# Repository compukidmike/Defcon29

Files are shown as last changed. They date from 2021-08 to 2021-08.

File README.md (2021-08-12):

# DEF CON 29 Badge
by MK Factor

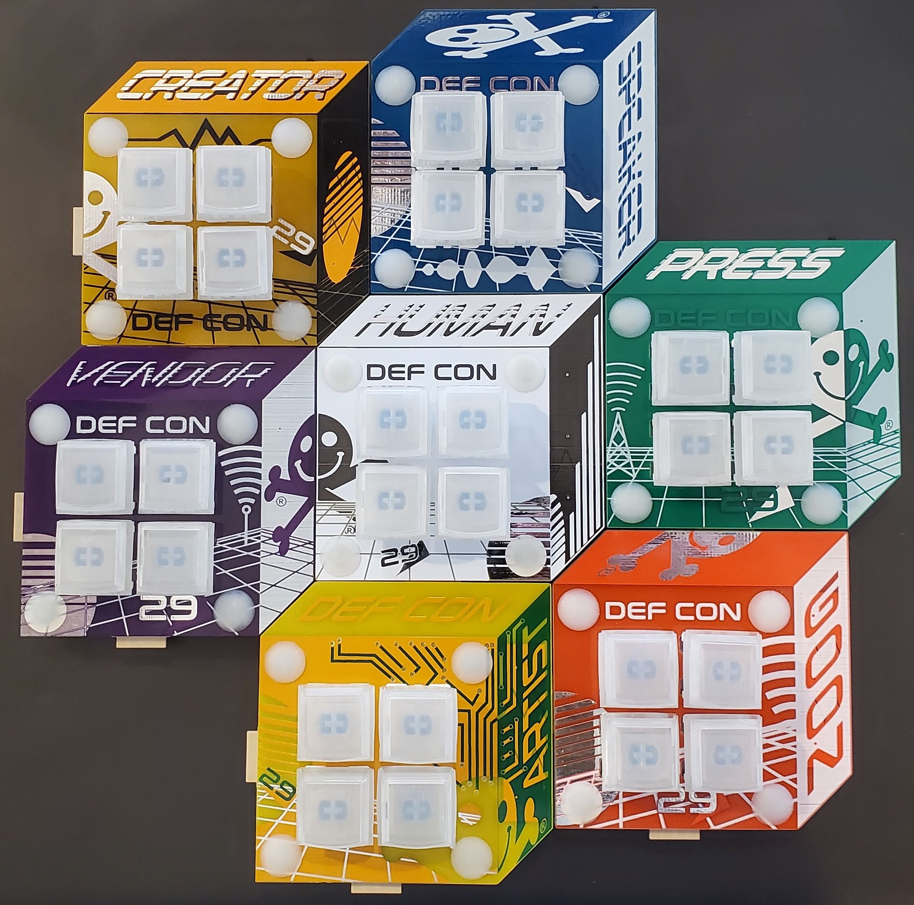
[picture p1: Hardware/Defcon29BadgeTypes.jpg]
Badge Types


Here's the code and some design files for the DEF CON 29 badge. Feel free to modify and share to your heart's content.

Compiled .uf2 files can be found under Firmware/Compiled. These are the firmware files that were released during the con that fix the 31-character issue. To put them on your badge, hold the bottom-right button when plugging it into your computer. The badge will start up in bootloader mode and will appear as a mass storage device. Drag/Drop or Copy/Paste the new .uf2 file onto the badge. It will apply the new firmware and automatcially restart.

NOTE: Flashing new firmware should not reset your challenge/game stats. They are stored in a separate EEPROM location in flash.

To generate your own .uf2 files, take the compiled .hex file and use the UF2 converter uf2conv.py available from https://github.com/microsoft/uf2/ (in the utils directory).

I wrote the code in ~~Atmel~~Microchip Studio 7.0 and used the ASF Framework. The install files for the version I used is available on the DEF CON Media Server
https://media.defcon.org/DEF%20CON%2029/DEF%20CON%2029%20badge/

The main microcontroller is an ATSAMD21G16B. It has 64KB of flash and 8KB of RAM. The first 8KB of flash is used for the bootloader, leaving 56KB for the main program. The bootloader is write protected by internal fuses in the microcontroller. If you want to remove it, you'll need to use an SWD programmer or write your own program that unlocks the booloader section and erases/overwrites it. Do this at your own risk.

Pull requests *may* be merged if they add functionality while retaining all original functionality. If you make something cool that doesn't fit this description, let me know and I'll try to add it to the list here.

## Cool Things Other People Have Made For The Badge ##
(I have not verified/tested any of these. Use at your own risk) 
* Music - https://github.com/duck-37/dc29-badge-stuff

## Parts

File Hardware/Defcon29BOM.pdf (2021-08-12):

DEF CON 29 Badge BOM
Bottom Side
Item | Qty Reference | Manufacturer | Manuf. Part # | Link
1 | 1 BT1 | Keystone Electronics | 3034TR | https://www.digikey.com/product-detail/en/keystone-electronics/3034TR/36-3034CT-ND/4833649
2 | 1 J5 | Adam Tech | USB-A-S-RA-TSMT | https://www.digikey.com/product-detail/en/adam-tech/USB-A-S-RA-TSMT/2057-USB-A-S-RA-TSMT-ND/9832331
3 | 4 SW1, SW2, SW3, SW4 | Gateron | KS-2P02B01-01 | https://kbdfans.com/products/gateron-hot-swap-pcb-socket

Top Side
Item | Qty Reference | Manufacturer | Manuf. Part # | Link
1 | 1 BZ1 | Murata Electronics | PKMCS0909E4000-R1 | https://www.digikey.com/product-detail/en/murata-electronics/PKMCS0909E4000-R1/490-9647-1-ND/4878401
2 | 4 C1, C2, C3, C4 | Kemet | C0603C104M4RACTU | https://www.digikey.com/en/products/detail/kemet/C0603C104M4RACTU/411098
3 | 3 C5, C6, C7 | Samsung Electro-Mechanics CL10A105KQ8NNNC | https://www.digikey.com/en/products/detail/samsung-electro-mechanics/CL10A105KQ8NNNC/3886694
4 | 4 D1, D2, D3, D4 | Everlight Electronics Co Ltd | 19-337C/RSBHGHC-A88/4T | https://www.digikey.com/en/products/detail/everlight-electronics-co-ltd/19-337C-RSBHGHC-A88-4T/10059590
5 | 2 J1, J3 | AVX Corporation | 109159004101116 | https://www.digikey.com/product-detail/en/avx-corporation/109159004101116/478-5675-1-ND/2080204
6 | 2 J2, J4 | AVX Corporation | 209159004101116 | https://www.digikey.com/product-detail/en/avx-corporation/209159004101116/478-5680-1-ND/2080209
7 | 3 RN1, RN2, RN3 | Bourns Inc. | CAY16-100J4LF | https://www.digikey.com/en/products/detail/bourns-inc/CAY16-100J4LF/3437837
8 | 1 RN4 | Bourns Inc. | CAY16-512J4LF | https://www.digikey.com/product-detail/en/bourns-inc/CAY16-512J4LF/CAY16-512J4LFCT-ND/3767810
9 | 2 | RN5, RN6 | Bourns Inc. | CAY16-101J4LF | https://www.digikey.com/en/products/detail/bourns-inc/CAY16-101J4LF/3437835
10 | 3 | SLIDER1, SLIDER2, SLIDER3 | ITT Cannon, LLC | 120220-0206 | https://www.digikey.com/product-detail/en/itt-cannon-llc/120220-0206/1003-1012-1-ND/2404035
11 | 1 | SW5 | C&K | JS202011JAQN | https://www.digikey.com/product-detail/en/c-k/JS202011JAQN/CKN10722CT-ND/6137636
12 | 1 | U1 | Microchip | ATSAMD21G16B-AU | https://www.digikey.com/en/products/detail/microchip-technology/ATSAMD21G16B-AU/5325402
13 | 1 | U2 | ON Semiconductor | NCP115ASN330T2G | https://www.digikey.com/product-detail/en/on-semiconductor/NCP115ASN330T2G/NCP115ASN330T2GOSCT-ND/9764887
14 | 1 | U3 | Torex Semiconductor Ltd | XBP15SRV05W-G | https://www.digikey.com/product-detail/en/torex-semiconductor-ltd/XBP15SRV05W-G/893-1422-1-ND/8256124
15 | 1 | X1 | IC components Store | Unknown | https://www.aliexpress.com/item/32962997618.html

Other Parts
Item | Qty | Reference | Manufacturer | Manuf. Part # | Link
1 | 4 | Keyswitches 1-4 | Gateron | Gateron Blue SMD | https://kbdfans.com/collections/gateron-swithes/products/smd-gateron-swtich
2 | 4 | Spacers 1-4 | transkoot | G216-03 | https://www.aliexpress.com/item/32844434973.html
3 | 4 | Keycaps 1-4 | MK Factor | Custom | STL available on DEF CON Media Server

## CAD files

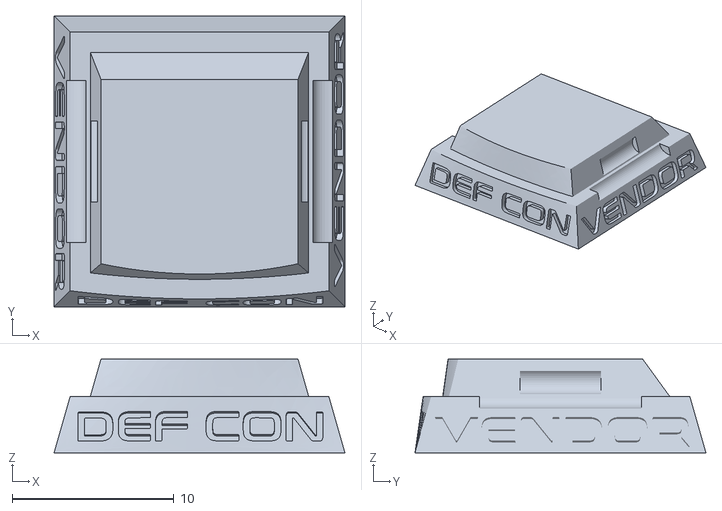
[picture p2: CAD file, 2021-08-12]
Hardware/Keycaps/Keycap-Bottom-Vendor.stl
18.0 x 18.0 x 5.80

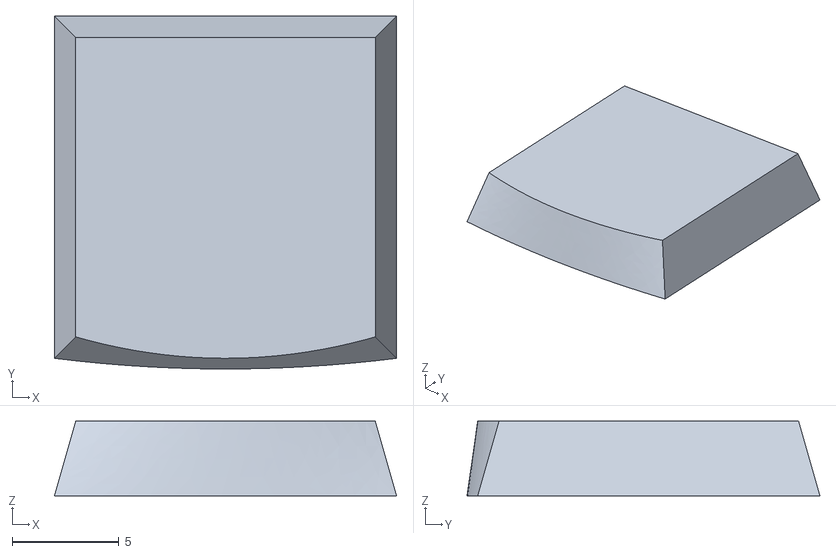
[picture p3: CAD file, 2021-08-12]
Hardware/Keycaps/Keycap-Top.stl
16.0 x 16.5 x 3.50

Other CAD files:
Hardware/Keycaps/Keycap-Bottom-Press.stl
Hardware/Keycaps/Keycap-Bottom-Artist.stl
Hardware/Keycaps/Keycap-Bottom-Human.stl
Hardware/Keycaps/Keycap-Bottom-Creator.stl
Hardware/Keycaps/Keycap-Source-FreeCad.FCStd
Hardware/Keycaps/Keycap-Bottom-Goon.stl
Hardware/Keycaps/Keycap-Bottom-Speaker.stl

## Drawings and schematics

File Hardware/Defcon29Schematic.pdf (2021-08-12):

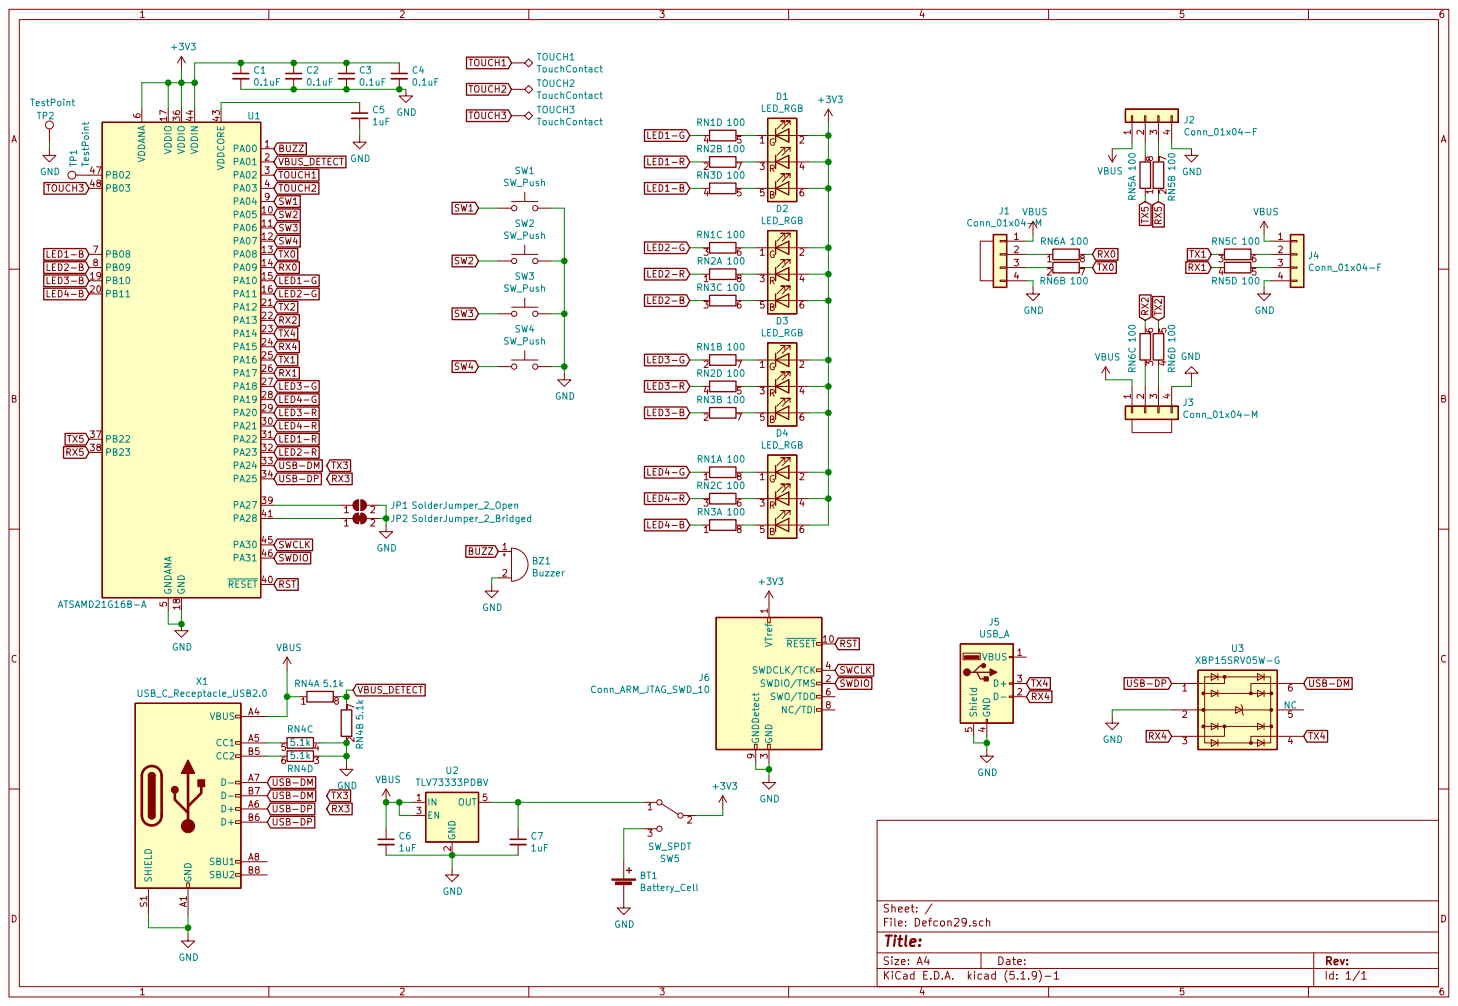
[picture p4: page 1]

2 EN 3 OUT 5 U2 TLV73333PDBV GND GND
SW4 SW_Push C7

3 SWDCLK/TCK 4 SWO/TDO 6 NC/TDI 8 GNDDetect 9

Id: 1/1 Title: File: Defcon29.sch Sheet: / GND

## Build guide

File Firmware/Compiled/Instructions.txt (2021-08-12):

The dc29boot.hex is the bootloader. It requires a SWD programmer connected to the Tag-Connect port on the badge. This only needs to be done once on a new chip.
The .uf2 files can be flashed with just a USB cable. Hold the bottom-right button when connecting the USB cable. The badge will enter the bootloader (top-left LED will blink red). It will appear as a mass storage device on your computer. You can then drag/drop the new uf2 firmware file onto it. The badge will automatically reboot when the update is complete.
NOTE: flashing new firmware will NOT reset your challenge/game status (unless you create custom firmware to overwrite the EEPROM).

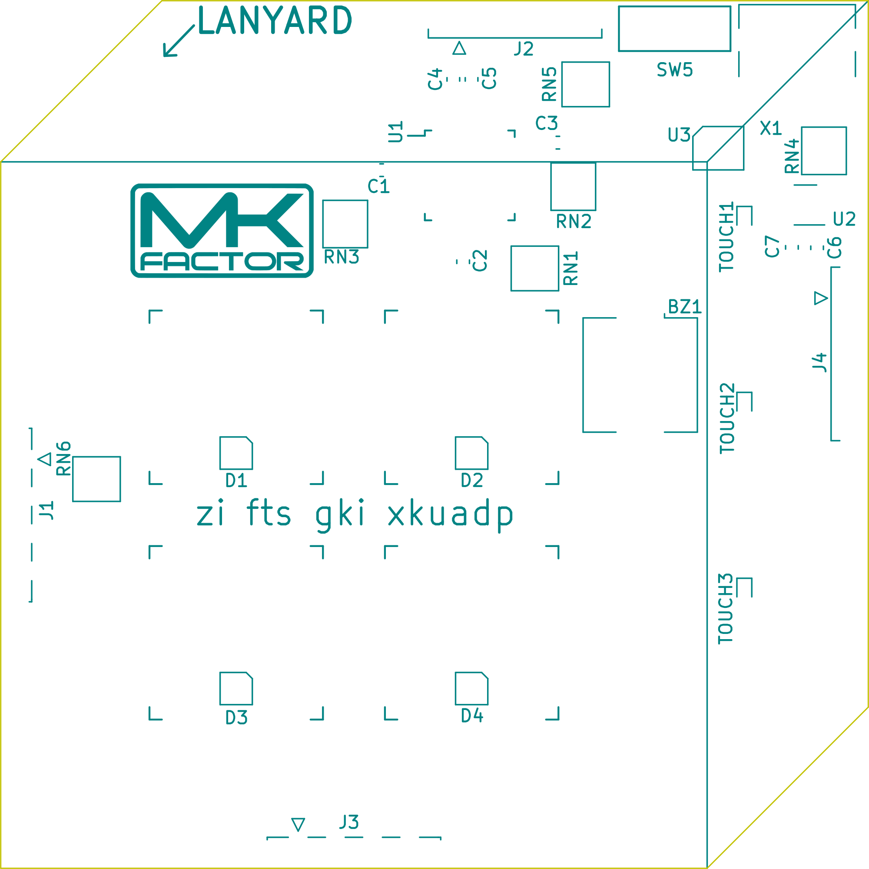
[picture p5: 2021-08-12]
Hardware/Defcon29-TopAssembly.png

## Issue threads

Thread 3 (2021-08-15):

Simon says sounds

miketweaver, 2021-08-15:
When you play Simon says the sound the game makes and then when you press the button aren't the same.

This probably is a bug

compukidmike, 2021-08-15:
This is a very interesting problem. The buzzer code is exactly the same for both, so I'm not sure why there's a difference. The main oscillator varies a lot with battery voltage, so that's possibly where it's coming from, but the LED is on in both situations, so it should be the same. If anyone has ideas, I'm all ears.

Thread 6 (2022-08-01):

Request: USB bulk transfer

skintigh, 2022-08-01:
I'd like to modify a button so the badge can connect to a USB peripheral that appears as a "mass storage device" and then do a number of sequences of reads and writes of 16 or 31 bytes. I know the vendor/device IDs.

Are there any examples you could share or pointers you could give me around MSC or bulk transfers?

I see you've commented out a lot of code dealing with udi_msc. I assume undoing that is the first step, then finding/following examples.
Thanks!

compukidmike, 2022-08-01:
I never played with the host mode, only device mode. In Microchip Studio, the ASF Wizard will allow you to add the necessary modules for USB host mode. The udc_stop() command should turn off the USB device mode so that you can re-configure the USB hardware for host mode. Good luck!

skintigh, 2022-08-03:
Do you have any hints on how to write raw data to USB?

I've gone through their docs and tried dozens of functions. They have 440 functions for reading/writing bytes to USB, and not a single working example nor description of required setup that I can find.

compukidmike, 2022-08-03:
Unfortunately I don't, sorry. I just used the USB serial example and slightly modified it for my needs.

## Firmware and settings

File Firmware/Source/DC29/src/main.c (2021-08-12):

/**
 * \file
 *
 * \brief Main functions for Keyboard example
 *
 * Copyright (c) 2009-2018 Microchip Technology Inc. and its subsidiaries.
 *
 * \asf_license_start
 *
 * \page License
 *
 * Subject to your compliance with these terms, you may use Microchip
 * software and any derivatives exclusively with Microchip products.
 * It is your responsibility to comply with third party license terms applicable
 * to your use of third party software (including open source software) that
 * may accompany Microchip software.
 *
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
 * \asf_license_stop
 *
 */
/*
 * Support and FAQ: visit <a href="https://www.microchip.com/support/">Microchip Support</a>
 */

#include <asf.h>
#include <stdbool.h>
#include "main.h"
#include "conf_usb.h"
#include "udi_hid_kbd.h"
#include "ui.h"

#include <pinmux.h>
#include <nvm.h>
#include "pwm.h"
#include <rww_eeprom.h>
#include "keys.h"
#include "serialconsole.h"
#include "games.h"



static volatile bool main_b_kbd_enable = false;

enum status_code eepromstatus;

/**
 * RTC Interrupt timing definition
 */
#define TIME_PERIOD_1MSEC 33u
#define TIME_PERIOD_500MSEC 16500u
/**
 * Variables
 */

uint32_t serialnum[4];

bool USBPower = false;


uint8_t rotor_state;
uint8_t rotor_position;
volatile uint8_t PWM_Count;
volatile uint32_t touch_time_counter = 0u;
struct rtc_module rtc_instance;

volatile uint32_t millis = 0;

volatile uint32_t buzzer_counter = 0;
volatile uint32_t buzzer_overflow = 250;
volatile bool buzzer_state = false;
volatile bool buzzer_skip = false;

bool main_b_cdc_enable = false;

uint8_t led1color[3];
uint8_t led2color[3];
uint8_t led3color[3];
uint8_t led4color[3];
uint8_t led1pressedcolor[3];
uint8_t led2pressedcolor[3];
uint8_t led3pressedcolor[3];
uint8_t led4pressedcolor[3];

volatile bool wait_for_sof = false;

volatile bool button1 = false;
volatile bool button2 = false;
volatile bool button3 = false;
volatile bool button4 = false;

#define DEBOUNCE_TIME 200
volatile uint32_t lastButton1Press = 0;
volatile uint32_t lastButton2Press = 0;
volatile uint32_t lastButton3Press = 0;
volatile uint32_t lastButton4Press = 0;

uint8_t keymap[231];
uint8_t keymaplength;
uint8_t keymapstarts[6];

uint8_t fwversion[1];

serial serialnumlist;

//Challenge challengedata;
ChallengeStruct challengedata;

//Game gamedata;
GameStruct gamedata;

GameModes gamemode;

extern struct tcc_module tcc2_instance;

volatile bool games_buzzer_off = true;
volatile uint32_t last_usb_comms = 0;

/* Macros */

/**
 * \def GET_SENSOR_STATE(SENSOR_NUMBER)
 * \brief To get the sensor state that it is in detect or not
 * \param SENSOR_NUMBER for which the state to be detected
 * \return Returns either 0 or 1
 * If the bit value is 0, it is not in detect
 * If the bit value is 1, it is in detect
 * Alternatively, the individual sensor state can be directly accessed using
 * p_qm_measure_data->p_sensor_states[(SENSOR_NUMBER/8)] variable.
 */
 #define GET_SELFCAP_SENSOR_STATE(SENSOR_NUMBER) p_selfcap_measure_data-> \
	p_sensor_states[(SENSOR_NUMBER / \
	8)] & (1 << (SENSOR_NUMBER % 8))

/**
 * \def GET_ROTOR_SLIDER_POSITION(ROTOR_SLIDER_NUMBER)
 * \brief To get the rotor angle or slider position.
 * These values are valid only when the sensor state for
 * corresponding rotor or slider shows in detect.
 * \param ROTOR_SLIDER_NUMBER for which the position to be known
 * \return Returns rotor angle or sensor position
 */
#define GET_SELFCAP_ROTOR_SLIDER_POSITION(ROTOR_SLIDER_NUMBER) \
	p_selfcap_measure_data->p_rotor_slider_values[ \
		ROTOR_SLIDER_NUMBER]


/* Interrupt on "pin change" from push button to do wakeup on USB
 * Note:
 * This interrupt is enable when the USB host enable remote wakeup feature
 * This interrupt wakeup the CPU if this one is in idle mode
 */
/*static void ui_wakeup_handler(void)
{
	// It is a wakeup then send wakeup USB 
	udc_remotewakeup();
	//LED_On(PIN_PA19);
}*/

void vbus_handler(void){
	if(port_pin_get_input_level(USB_VBUS_PIN)){
		// Start USB stack to authorize VBus monitoring
		disable_usart_top();
		udc_start();
		USBPower = true;
		//configure_usart_top_default();
	} else {
		//disable_usart_top();
		udc_stop();
		configure_usart_top_usb();
		USBPower = false;
	}
}

/*! \brief Main function. Execution starts here.
 */
int main(void)
{
	//Get chip serial number. We only use the last 4 bytes to save EEPROM space and to make comms faster
	serialnum[0] = *(volatile uint32_t *)0x0080A040;
	serialnum[1] = *(volatile uint32_t *)0x0080A044;
	serialnum[2] = *(volatile uint32_t *)0x0080A048;
	serialnum[3] = *(volatile uint32_t *)0x0080A00C;
	
	eepromstatus = rww_eeprom_emulator_init();
	if(eepromstatus == STATUS_ERR_BAD_FORMAT){
		rww_eeprom_emulator_erase_memory();
		rww_eeprom_emulator_init();
	}

	rww_eeprom_emulator_read_buffer(EEP_FIRMWARE_VERSION, fwversion, 1);
	
	if(fwversion[0] != FIRMWARE_VERSION){ //Clear eeprom and re-init with good values
		reset_eeprom();
	}
	
	read_eeprom();
	
	
	//uint8_t button1_state;
	//uint8_t button2_state;
	uint8_t slider_state;
	uint8_t slider_position;
	uint8_t last_slider_position;
	
	irq_initialize_vectors();
	cpu_irq_enable();

	// Initialize the sleep manager
	//sleepmgr_init();

#if !SAM0
	sysclk_init();
	board_init();
#else
	system_init();
#endif

	//Enable GCLK Generator 3
	SYSCTRL->VREG.bit.RUNSTDBY = 1;
	
	// Configure GCLK3's divider - in this case, no division - so just divide by one /
	GCLK->GENDIV.reg =
	GCLK_GENDIV_ID(3) |
	GCLK_GENDIV_DIV(1);

	// Setup GCLK3 using the internal 8 MHz oscillator /
	GCLK->GENCTRL.reg =
	GCLK_GENCTRL_ID(3) |
	GCLK_GENCTRL_SRC_OSC8M |
	// Improve the duty cycle. /
	GCLK_GENCTRL_IDC |
	GCLK_GENCTRL_GENEN |
	GCLK_GENCTRL_RUNSTDBY;

	// Wait for the write to complete /
	while(GCLK->STATUS.bit.SYNCBUSY) {};
		
	// Connect GCLK3 to SERCOM0 /
	GCLK->CLKCTRL.reg =
	GCLK_CLKCTRL_CLKEN |
	GCLK_CLKCTRL_GEN_GCLK3 |
	GCLK_CLKCTRL_ID_SERCOM0_CORE;

	// Wait for the write to complete. /
	while (GCLK->STATUS.bit.SYNCBUSY) {};
	
	delay_init();
	sleepmgr_init();
	
	
	struct port_config pin_conf;
	port_get_config_defaults(&pin_conf);
	

	/* Set buttons as inputs */
	pin_conf.direction  = PORT_PIN_DIR_INPUT;
	pin_conf.input_pull = PORT_PIN_PULL_UP;
	port_pin_set_config(BUTTON1, &pin_conf);
	port_pin_set_config(BUTTON2, &pin_conf);
	port_pin_set_config(BUTTON3, &pin_conf);
	port_pin_set_config(BUTTON4, &pin_conf);
	
	port_pin_set_config(MATRIX, &pin_conf);
	port_pin_set_config(MAX, &pin_conf);
	port_pin_set_config(ALIENS, &pin_conf);
	
	pin_conf.input_pull = PORT_PIN_PULL_DOWN;
	port_pin_set_config(USB_VBUS_PIN, &pin_conf);
	
	
	//Setup Pin Interrupts
	struct extint_chan_conf config_extint_chan;
	extint_chan_get_config_defaults(&config_extint_chan);
	
	//VBUS pin interrupt
	config_extint_chan.gpio_pin            = PIN_PA01A_EIC_EXTINT1;
	config_extint_chan.gpio_pin_mux        = PINMUX_PA01A_EIC_EXTINT1;
	config_extint_chan.gpio_pin_pull       = EXTINT_PULL_DOWN;
	config_extint_chan.filter_input_signal = true;
	config_extint_chan.detection_criteria  = EXTINT_DETECT_BOTH;
	extint_chan_set_config(1, &config_extint_chan);
	extint_register_callback(vbus_handler, 1, EXTINT_CALLBACK_TYPE_DETECT);
	extint_chan_enable_callback(1,EXTINT_CALLBACK_TYPE_DETECT);

	//Button 1 interrupt
	config_extint_chan.gpio_pin            = PIN_PA04A_EIC_EXTINT4;
	config_extint_chan.gpio_pin_mux        = PINMUX_PA04A_EIC_EXTINT4;
	config_extint_chan.gpio_pin_pull       = EXTINT_PULL_UP;
	config_extint_chan.filter_input_signal = true;
	config_extint_chan.detection_criteria  = EXTINT_DETECT_FALLING;
	extint_chan_set_config(4, &config_extint_chan);
	extint_register_callback(button1_handler, 4, EXTINT_CALLBACK_TYPE_DETECT);
	extint_chan_enable_callback(4,EXTINT_CALLBACK_TYPE_DETECT);
	
	//Button 2 interrupt
	config_extint_chan.gpio_pin            = PIN_PA05A_EIC_EXTINT5;
	config_extint_chan.gpio_pin_mux        = PINMUX_PA05A_EIC_EXTINT5;
	config_extint_chan.gpio_pin_pull       = EXTINT_PULL_UP;
	config_extint_chan.filter_input_signal = true;
	config_extint_chan.detection_criteria  = EXTINT_DETECT_FALLING;
	extint_chan_set_config(5, &config_extint_chan);
	extint_register_callback(button2_handler, 5, EXTINT_CALLBACK_TYPE_DETECT);
	extint_chan_enable_callback(5,EXTINT_CALLBACK_TYPE_DETECT);
	
	//Button 3 interrupt
	config_extint_chan.gpio_pin            = PIN_PA06A_EIC_EXTINT6;
	config_extint_chan.gpio_pin_mux        = PINMUX_PA06A_EIC_EXTINT6;
	config_extint_chan.gpio_pin_pull       = EXTINT_PULL_UP;
	config_extint_chan.filter_input_signal = true;
	config_extint_chan.detection_criteria  = EXTINT_DETECT_FALLING;
	extint_chan_set_config(6, &config_extint_chan);
	extint_register_callback(button3_handler, 6, EXTINT_CALLBACK_TYPE_DETECT);
	extint_chan_enable_callback(6,EXTINT_CALLBACK_TYPE_DETECT);
	
	//Button 4 interrupt
	config_extint_chan.gpio_pin            = PIN_PA07A_EIC_EXTINT7;
	config_extint_chan.gpio_pin_mux        = PINMUX_PA07A_EIC_EXTINT7;
	config_extint_chan.gpio_pin_pull       = EXTINT_PULL_UP;
	config_extint_chan.filter_input_signal = true;
	config_extint_chan.detection_criteria  = EXTINT_DETECT_FALLING;
	extint_chan_set_config(7, &config_extint_chan);
	extint_register_callback(button4_handler, 7, EXTINT_CALLBACK_TYPE_DETECT);
	extint_chan_enable_callback(7,EXTINT_CALLBACK_TYPE_DETECT);
	
	timer_init();
	
	configure_usart();
	configure_usart_callbacks();
	
	
	if(port_pin_get_input_level(USB_VBUS_PIN)){
		// Start USB stack to authorize VBus monitoring
		//disable_usart_top();
		udc_start();
		USBPower = true;
		//configure_usart_top_default();
		} else {
		//disable_usart_top();
		//udc_stop();
		configure_usart_top_usb();
		USBPower = false;
	}
	
	GCLK->GENCTRL.bit.RUNSTDBY = 1;  //GCLK run standby
	
	touch_sensors_init();
	
	pwm_init();
	
	//Startup LED Sequence
	uint8_t delaytime = 40;
	led_on(LED1R);
	delay_cycles_ms(delaytime);
	led_on(LED2R);
	delay_cycles_ms(delaytime);
	led_on(LED3R);
	delay_cycles_ms(delaytime);
	led_on(LED4R);
	delay_cycles_ms(delaytime);
	led_off(LED1R);
	led_on(LED1G);
	delay_cycles_ms(delaytime);
	led_off(LED2R);
	led_on(LED2G);
	delay_cycles_ms(delaytime);
	led_off(LED3R);
	led_on(LED3G);
	delay_cycles_ms(delaytime);
	led_off(LED4R);
	led_on(LED4G);
	delay_cycles_ms(delaytime);
	led_off(LED1G);
	led_on(LED1B);
	delay_cycles_ms(delaytime);
	led_off(LED2G);
	led_on(LED2B);
	delay_cycles_ms(delaytime);
	led_off(LED3G);
	led_on(LED3B);
	delay_cycles_ms(delaytime);
	led_off(LED4G);
	led_on(LED4B);
	delay_cycles_ms(delaytime);
	led_off(LED1B);
	delay_cycles_ms(delaytime);
	led_off(LED2B);
	delay_cycles_ms(delaytime);
	led_off(LED3B);
	delay_cycles_ms(delaytime);
	led_off(LED4B);
	
	if(!port_pin_get_input_level(BUTTON1)){
		gamemode = SIMON_SOLO;
		led_set_color(1,LED_COLOR_OFF);
		led_set_color(2,LED_COLOR_OFF);
		led_set_color(3,LED_COLOR_OFF);
		led_set_color(4,LED_COLOR_OFF);
		while(port_pin_get_input_level(BUTTON1) == false);
		button1 = false;
	}

	uart_event = millis;
	
	led_set_color(1,led1color);
	led_set_color(2,led2color);
	led_set_color(3,led3color);
	led_set_color(4,led4color);

	
	while(1){
		//Check Buttons
		if(gamemode == IDLE){ //Game modes check the buttons themselves
			if(USBPower && ((millis - last_usb_comms) < 100)){ //Only send keys when connected to a computer
				if(button1){
					button1 = false;
					//if(main_b_kbd_enable) send_keys(1);
					send_keys(1);
				}
				if(button2){
					button2 = false;
					//if(main_b_kbd_enable) send_keys(2);
					send_keys(2);
				}
				if(button3){
					button3 = false;
					//if(main_b_kbd_enable) send_keys(3);
					send_keys(3);
				}
				if(button4){
					button4 = false;
					//if(main_b_kbd_enable) send_keys(4);
					send_keys(4);
				}
			
				//Check Touch Sensors
				touch_sensors_measure();
				if (p_selfcap_measure_data->measurement_done_touch == 1u) {

					p_selfcap_measure_data->measurement_done_touch = 0u;
					slider_state = GET_SELFCAP_SENSOR_STATE(0);
					if(slider_state)
					{
						slider_position = GET_SELFCAP_ROTOR_SLIDER_POSITION(0);
						if(slider_position > last_slider_position + 10){
							last_slider_position = slider_position;
							send_keys(6);//sliding down
						}
						if(slider_position < last_slider_position - 10){
							last_slider_position = slider_position;
							send_keys(5);//sliding up
						}
					}
				}
			}
		}
		
		//Update USB serial console if we got data
		if(main_b_cdc_enable){
			if(udi_cdc_get_nb_received_data()){
				updateSerialConsole();
			}
		}
		
		//Go to sleep to save battery
		//if (!USBPower && ((uart_event + 1000) < millis)) {
		if (!USBPower && ((millis - uart_event) > 1000) && gamemode != SIMON_SOLO) {
			standby_sleep();
		}
		
		
		//Check serial ports
		check_comms();
		
		run_games();
		
		play_sounds();
	}
}


void send_data(void){
	const uint16_t data = 1;
	uint8_t delay = 50;
	usart_write_job(&usart_top_instance, &data);
	delay_cycles_ms(delay);
	usart_write_job(&usart_right_instance, &data);
	delay_cycles_ms(delay);
	usart_write_job(&usart_bottom_instance, &data);
	delay_cycles_ms(delay);
	usart_write_job(&usart_left_instance, &data);
	delay_cycles_ms(delay);
	usart_write_job(&usart_usba_instance, &data);
	delay_cycles_ms(delay);
	usart_write_job(&usart_usbc_instance, &data);
	delay_cycles_ms(delay);
}

void main_suspend_action(void)
{
	//ui_powerdown();
}

void main_resume_action(void) 
{
	//ui_wakeup();
}

//void main_sof_action(void)
void user_callback_sof_action(void)
{
	wait_for_sof = false;
	last_usb_comms = millis;
}

void main_remotewakeup_enable(void)
{
	//ui_wakeup_enable();
}

void main_remotewakeup_disable(void)
{
	//ui_wakeup_disable();
}

//bool main_kbd_enable(void)
void user_callback_vbus_action(bool b_vbus_high)
{
	main_b_kbd_enable = b_vbus_high;
	if(main_b_kbd_enable){
		disable_usart_top();
		configure_usart_top_default();
	} else {
		disable_usart_top();
		configure_usart_top_usb();
	}
}

void main_kbd_disable(void)
{
	main_b_kbd_enable = false;
}

/*! \brief Configure the RTC timer overflow callback
 *
 */
void rtc_overflow_callback(void)
{
	millis ++;
	
	/* Do something on RTC overflow here */
	if(touch_time_counter == touch_time.measurement_period_ms)
	{
		touch_time.time_to_measure_touch = 1;
		touch_time.current_time_ms = touch_time.current_time_ms +
		touch_time.measurement_period_ms;
		touch_time_counter = 0u;
	}
	else
	{
		touch_time_counter++;
	}
	
	if(gamemode == SIMON_SOLO || gamemode == SIMON_MULTI_PRIMARY || gamemode == SIMON_MULTI_SECONDARY){
		if(!port_pin_get_input_level(BUTTON1)){
			tcc_restart_counter(&tcc2_instance);
			tcc_set_compare_value(&tcc2_instance,0,219); //415Hz
			
			led_set_color(1,LED_COLOR_GREEN);
		}
		if(!port_pin_get_input_level(BUTTON2)){
			tcc_restart_counter(&tcc2_instance);
			tcc_set_compare_value(&tcc2_instance,0,293); //310Hz
			
			led_set_color(2,LED_COLOR_RED);
		}
		if(!port_pin_get_input_level(BUTTON3)){
			tcc_restart_counter(&tcc2_instance);
			tcc_set_compare_value(&tcc2_instance,0,360); //252Hz
			
			led_set_color(3,LED_COLOR_YELLOW);
		}
		if(!port_pin_get_input_level(BUTTON4)){
			tcc_restart_counter(&tcc2_instance);
			tcc_set_compare_value(&tcc2_instance,0,435); //209Hz
			
			led_set_color(4,LED_COLOR_BLUE);
		}
	
		if(port_pin_get_input_level(BUTTON1) & port_pin_get_input_level(BUTTON2) & port_pin_get_input_level(BUTTON3) & port_pin_get_input_level(BUTTON4) & games_buzzer_off){
			//tcc_set_compare_value(&tcc2_instance,0,0); //off
			tcc_stop_counter(&tcc2_instance);
			led_set_color(1,LED_COLOR_OFF);
			led_set_color(2,LED_COLOR_OFF);
			led_set_color(3,LED_COLOR_OFF);
			led_set_color(4,LED_COLOR_OFF);
		}
	}
}

/*! \brief Configure the RTC timer callback
 *
 */
void configure_rtc_callbacks(void)
{
	/* register callback */
	rtc_count_register_callback(&rtc_instance,
			rtc_overflow_callback, RTC_COUNT_CALLBACK_OVERFLOW);
	/* Enable callback */
	rtc_count_enable_callback(&rtc_instance,RTC_COUNT_CALLBACK_OVERFLOW);
}

/*! \brief Configure the RTC timer count after which interrupts comes
 *
 */
void configure_rtc_count(void)
{
	struct rtc_count_config config_rtc_count;
	rtc_count_get_config_defaults(&config_rtc_count);

	config_rtc_count.prescaler           = RTC_COUNT_PRESCALER_DIV_1;
	config_rtc_count.mode                = RTC_COUNT_MODE_16BIT;
	config_rtc_count.continuously_update = true;
	/* initialize rtc */
	rtc_count_init(&rtc_instance,RTC,&config_rtc_count);

	/* enable rtc */
	rtc_count_enable(&rtc_instance);
}
/*! \brief Initialize timer
 *
 */
void timer_init(void)
{
	/* Configure and enable RTC */
	configure_rtc_count();

	/* Configure and enable callback */
	configure_rtc_callbacks();

	/* Set Timer Period */

	rtc_count_set_period(&rtc_instance,TIME_PERIOD_1MSEC);
}

void button1_handler(void){
	if(button1 == false){
		if((millis - lastButton1Press) > DEBOUNCE_TIME){
			lastButton1Press = millis;
			button1 = true;
			uart_event = millis;
		}
	}
}

void button2_handler(void){
	if(button2 == false){
		if((millis - lastButton2Press) > DEBOUNCE_TIME){
			lastButton2Press = millis;
			button2 = true;
		}
	}
}

void button3_handler(void){
	if(button3 == false){
		if((millis - lastButton3Press) > DEBOUNCE_TIME){
			lastButton3Press = millis;
			button3 = true;
		}
	}
}

void button4_handler(void){
	if(button4 == false){
		if((millis - lastButton4Press) > DEBOUNCE_TIME){
			lastButton4Press = millis;
			button4 = true;
		}
	}
}

bool main_cdc_enable(uint8_t port)
{
	main_b_cdc_enable = true;
	// Open communication
	//uart_open(port);
	return true;
}

void main_cdc_disable(uint8_t port)
{
	main_b_cdc_enable = false;
	// Close communication
	//uart_close(port);
}

void main_cdc_set_dtr(uint8_t port, bool b_enable)
{
	if (b_enable) {
		// Host terminal has open COM
		//ui_com_open(port);
		}else{
		// Host terminal has close COM
		//ui_com_close(port);
	}
}

void reset_eeprom(void){ //reset entire EEPROM including challenge and game data
	rww_eeprom_emulator_erase_memory();
	rww_eeprom_emulator_init();
	fwversion[0] = FIRMWARE_VERSION;
	rww_eeprom_emulator_write_buffer(EEP_FIRMWARE_VERSION, fwversion, 1);
	uint8_t eepdata[1];
	eepdata[0] = 0;
	for(int x=1; x<EEP_LED_BRIGHTNESS; x++){
		rww_eeprom_emulator_write_buffer(x, eepdata, 1);
	}
	uint8_t leddata[3];
	leddata[0] = 255; //full brightness as default
	rww_eeprom_emulator_write_buffer(EEP_LED_BRIGHTNESS, leddata, 1);
	leddata[0] = 255;
	leddata[1] = 0;
	leddata[2] = 0;
	rww_eeprom_emulator_write_buffer(EEP_LED_1_COLOR, leddata, 3);
	leddata[0] = 0;
	leddata[1] = 255;
	leddata[2] = 0;
	rww_eeprom_emulator_write_buffer(EEP_LED_2_COLOR, leddata, 3);
	leddata[0] = 0;
	leddata[1] = 0;
	leddata[2] = 255;
	rww_eeprom_emulator_write_buffer(EEP_LED_3_COLOR, leddata, 3);
	leddata[0] = 127;
	leddata[1] = 127;
	leddata[2] = 127;
	rww_eeprom_emulator_write_buffer(EEP_LED_4_COLOR, leddata, 3);
	leddata[0] = 0;
	leddata[1] = 127;
	leddata[2] = 127;
	rww_eeprom_emulator_write_buffer(EEP_LED_1_PRESSED_COLOR, leddata, 3);
	leddata[0] = 127;
	leddata[1] = 0;
	leddata[2] = 127;
	rww_eeprom_emulator_write_buffer(EEP_LED_2_PRESSED_COLOR, leddata, 3);
	leddata[0] = 127;
	leddata[1] = 127;
	leddata[2] = 0;
	rww_eeprom_emulator_write_buffer(EEP_LED_3_PRESSED_COLOR, leddata, 3);
	leddata[0] = 0;
	leddata[1] = 0;
	leddata[2] = 0;
	rww_eeprom_emulator_write_buffer(EEP_LED_4_PRESSED_COLOR, leddata, 3);
	
	rww_eeprom_emulator_write_buffer(EEP_KEY_MAP, default_keymap, sizeof(default_keymap));
	rww_eeprom_emulator_commit_page_buffer();
}

void reset_user_eeprom(void){ //Reset the LED and keymap data
	#if DEBUG > 0 //Reset badge challenge info in debug mode
	uint8_t bytes[80] = {0};
	rww_eeprom_emulator_write_buffer(EEP_CHALLENGE_CONNECTED_TYPES, bytes, 5);
	rww_eeprom_emulator_write_buffer(EEP_CHALLENGE_BADGE_SERIALS, bytes, 80);
	rww_eeprom_emulator_write_buffer(EEP_GAME_SIMON_SOLO_HIGH_SCORE, bytes, 18);
	#endif
	uint8_t leddata[3];
	leddata[0] = 255; //full brightness as default
	rww_eeprom_emulator_write_buffer(EEP_LED_BRIGHTNESS, leddata, 1);
	leddata[0] = 255;
	leddata[1] = 0;
	leddata[2] = 0;
	rww_eeprom_emulator_write_buffer(EEP_LED_1_COLOR, leddata, 3);
	leddata[0] = 0;
	leddata[1] = 255;
	leddata[2] = 0;
	rww_eeprom_emulator_write_buffer(EEP_LED_2_COLOR, leddata, 3);
	leddata[0] = 0;
	leddata[1] = 0;
	leddata[2] = 255;
	rww_eeprom_emulator_write_buffer(EEP_LED_3_COLOR, leddata, 3);
	leddata[0] = 127;
	leddata[1] = 127;
	leddata[2] = 127;
	rww_eeprom_emulator_write_buffer(EEP_LED_4_COLOR, leddata, 3);
	leddata[0] = 0;
	leddata[1] = 127;
	leddata[2] = 127;
	rww_eeprom_emulator_write_buffer(EEP_LED_1_PRESSED_COLOR, leddata, 3);
	leddata[0] = 127;
	leddata[1] = 0;
	leddata[2] = 127;
	rww_eeprom_emulator_write_buffer(EEP_LED_2_PRESSED_COLOR, leddata, 3);
	leddata[0] = 127;
	leddata[1] = 127;
	leddata[2] = 0;
	rww_eeprom_emulator_write_buffer(EEP_LED_3_PRESSED_COLOR, leddata, 3);
	leddata[0] = 0;
	leddata[1] = 0;
	leddata[2] = 0;
	rww_eeprom_emulator_write_buffer(EEP_LED_4_PRESSED_COLOR, leddata, 3);
	
	rww_eeprom_emulator_write_buffer(EEP_KEY_MAP, default_keymap, sizeof(default_keymap));
	rww_eeprom_emulator_commit_page_buffer();
	
	rww_eeprom_emulator_read_buffer(EEP_LED_1_COLOR, led1color, 3);
	led_set_color(1,led1color);
	rww_eeprom_emulator_read_buffer(EEP_LED_2_COLOR, led2color, 3);
	led_set_color(2,led2color);
	rww_eeprom_emulator_read_buffer(EEP_LED_3_COLOR, led3color, 3);
	led_set_color(3,led3color);
	rww_eeprom_emulator_read_buffer(EEP_LED_4_COLOR, led4color, 3);
	led_set_color(4,led4color);
}
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

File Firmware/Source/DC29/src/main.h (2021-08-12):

/**
 * \file
 *
 * \brief Declaration of main function used by HID keyboard example
 *
 * Copyright (c) 2009-2018 Microchip Technology Inc. and its subsidiaries.
 *
 * \asf_license_start
 *
 * \page License
 *
 * Subject to your compliance with these terms, you may use Microchip
 * software and any derivatives exclusively with Microchip products.
 * It is your responsibility to comply with third party license terms applicable
 * to your use of third party software (including open source software) that
 * may accompany Microchip software.
 *
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
 * \asf_license_stop
 *
 */
/*
 * Support and FAQ: visit <a href="https://www.microchip.com/support/">Microchip Support</a>
 */

#ifndef _MAIN_H_
#define _MAIN_H_

#include "asf.h"
#include "pwm.h"
#include "comms.h"
#include "games.h"



#define DEBUG 0 //debug code no longer fits in the available flash :(

#define FIRMWARE_VERSION 1 //Only change if EEPROM layout changes

//Badge Type can be:
// 1 = Human
// 2 = Goon
// 4 = Creator
// 8 = Speaker
// 16 = Artist
// 32 = Vendor
// 64 = Press
// 128 = UBER - DON'T DO THIS! It will break other badges!

#define BADGE_TYPE 1

#define BUTTON1 PIN_PA04
#define BUTTON2 PIN_PA05
#define BUTTON3 PIN_PA06
#define BUTTON4 PIN_PA07

#define LED1RPIN PIN_PA22
#define LED1GPIN PIN_PA10
#define LED1BPIN PIN_PB08
#define LED2RPIN PIN_PA23
#define LED2GPIN PIN_PA11
#define LED2BPIN PIN_PB09
#define LED3RPIN PIN_PA20
#define LED3GPIN PIN_PA18
#define LED3BPIN PIN_PB10
#define LED4RPIN PIN_PA21
#define LED4GPIN PIN_PA19
#define LED4BPIN PIN_PB11

#define BUZZER PIN_PB22

#define MATRIX PIN_PA28
#define MAX PIN_PA27
#define ALIENS PIN_PB02

#define LED_COLOR_OFF (uint8_t[]){0,0,0}
#define LED_COLOR_RED (uint8_t[]){255,0,0}
#define LED_COLOR_GREEN (uint8_t[]){0,255,0}
#define LED_COLOR_BLUE (uint8_t[]){0,0,255}
#define LED_COLOR_YELLOW (uint8_t[]){127,127,0}

//EEPROM Location Offsets
#define	EEP_FIRMWARE_VERSION 0 //1 BYTE

#define EEP_CHALLENGE_CONNECTED_TYPES 1 //1 BYTE
#define EEP_CHALLENGE_NUM_CONNECTED 2 //2 BYTES
#define EEP_CHALLENGE_NUM_SHARED 4 //2 BYTES
#define EEP_CHALLENGE_BADGE_SERIALS 6 //4 BYTES EACH, 20 BADGES, 80 BYTES TOTAL

#define NUM_BADGE_SERIALS 20

#define EEP_GAME_SIMON_SOLO_HIGH_SCORE 86 //2 BYTES
#define EEP_GAME_SIMON_MULTI_HIGH_SCORE 88 //2 BYTES
#define EEP_GAME_SIMON_MULTI_CONNECTIONS 90 //2 BYTES
#define EEP_GAME_SIMON_MULTI_GAMES_PLAYED 92 //2 BYTES
#define EEP_GAME_WAM_SOLO_HIGH_SCORE  94 //2 BYTES
#define EEP_GAME_WAM_MULTI_HIGH_SCORE 96 //2 BYTES
#define EEP_GAME_WAM_MULTI_CONNECTIONS 98 //2 BYTES
#define EEP_GAME_WAM_MULTI_GAMES_PLAYED 100 //2 BYTES
#define EEP_GAME_WAM_MULTI_WINS 102 //2 BYTES

#define EEP_LED_BRIGHTNESS 104 //1 BYTE
#define EEP_LED_1_COLOR 105 //3 BYTES
#define EEP_LED_2_COLOR 108 //3 BYTES
#define EEP_LED_3_COLOR 111 //3 BYTES
#define EEP_LED_4_COLOR 114 //3 BYTES
#define EEP_LED_1_PRESSED_COLOR 117 //3 BYTES
#define EEP_LED_2_PRESSED_COLOR 120 //3 BYTES
#define EEP_LED_3_PRESSED_COLOR 123 //3 BYTES
#define EEP_LED_4_PRESSED_COLOR 126 //3 BYTES

#define EEP_KEY_MAP 129 //MAX 231 BYTES (EEPROM is limited to 260 bytes)

typedef enum {
	IDLE,
	SELECT_GAME,
	SIMON_SOLO,
	SIMON_MULTI_PRIMARY,
	SIMON_MULTI_SECONDARY,
	WAM_SOLO,
	WAM_MULTI,
	WAIT_FOR_START,
} GameModes;

typedef struct {
	uint8_t badgetypes;
	uint16_t numconnected;
	uint16_t numshared;
} ChallengeStruct;

typedef union {
	uint32_t numbers[20];
	uint8_t bytes[80];
} serial;

typedef struct {
	uint16_t simon_solo_high_score;
	uint16_t simon_multi_high_score;
	uint16_t simon_multi_connections;
	uint16_t simon_multi_games_played;
	uint16_t wam_solo_high_score;
	uint16_t wam_multi_high_score;
	uint16_t wam_multi_connections;
	uint16_t wam_multi_games_played;
	uint16_t wam_multi_wins;
} GameStruct;

static const uint8_t default_keymap[21] = { 
	21, //length
	250,3,16, //key1 - ctrl-shift-m
	251,240,32, //key2 - Mute
	252,2,51,2,39, //key3 - :)
	253,240,16, //key4 - Play/Pause
	254,240,64,255,240,128 //slider Vol+/-
};
/*! \brief Called by HID interface
 * Callback running when USB Host enable keyboard interface
 *
 * \retval true if keyboard startup is ok
 */
bool main_kbd_enable(void);
//void user_callback_vbus_action(bool b_vbus_high);

/*! \brief Called by HID interface
 * Callback running when USB Host disable keyboard interface
 */
void main_kbd_disable(void);

/*! \brief Called when a start of frame is received on USB line
 */
void main_sof_action(void);
//void user_callback_sof_action(void);

/*! \brief Enters the application in low power mode
 * Callback called when USB host sets USB line in suspend state
 */
void main_suspend_action(void);

/*! \brief Called by UDD when the USB line exit of suspend state
 */
void main_resume_action(void);

/*! \brief Called by UDC when USB Host request to enable remote wakeup
 */
void main_remotewakeup_enable(void);

/*! \brief Called by UDC when USB Host request to disable remote wakeup
 */
void main_remotewakeup_disable(void);
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

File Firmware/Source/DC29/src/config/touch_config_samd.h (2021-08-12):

/* This source file is part of the ATMEL QTouch Library 5.0.1 */

/*****************************************************************************
 *
 * \file
 *
 * \brief  This file contains the SAMD QTouch Library pin, register and
 * sensors configuration options for Capacitive Touch acquisition using
 * the PTC module.
 *
 *
 * - Userguide:          QTouch Library Peripheral Touch Controller User Guide.
 * - Support: https://www.microchip.com/support/
 *
 *
 * Copyright (c) 2014-2018 Microchip Technology Inc. and its subsidiaries.
 *
 * \asf_license_start
 *
 * \page License
 *
 * Subject to your compliance with these terms, you may use Microchip
 * software and any derivatives exclusively with Microchip products.
 * It is your responsibility to comply with third party license terms applicable
 * to your use of third party software (including open source software) that
 * may accompany Microchip software.
 *
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
 * \asf_license_stop
 *
 ******************************************************************************/

#ifndef TOUCH_CONFIG_SAMD_H
#define TOUCH_CONFIG_SAMD_H

/*----------------------------------------------------------------------------
*                   Self Cap method enable/disable.
*  ----------------------------------------------------------------------------*/

/**
 * Enable/Disable Self/Mutual Capacitance method.
 */
#define DEF_TOUCH_SELFCAP               (1)
#define DEF_TOUCH_MUTLCAP               (0)

/*----------------------------------------------------------------------------
*                   PTC module clock and interrupt level configuration.
*  ----------------------------------------------------------------------------*/

/**
 * PTC Module clock configuration.
 * Before using the QTouch library API, the PTC module clock generator source
 * should be configured appropriately.  The PTC module clock can be generated
 * using any of the eight generic clock generators (GCLK0-GCLK7).  The associated
 * generic clock multiplexer should be configured such that the PTC module clock
 * is set to 4MHz.  Refer touch_configure_ptc_clock API in touch.c for more
 * information.
 */

/**
 * PTC Module interrupt level.
 * The Nested Vectored Interrupt Controller (NVIC) in the SAMD supports
 * four different priority levels.  The priority level of the PTC end of
 * conversion ISR, used within QTouch library can be chosen based on application
 * requirements in order to accommodate time critical operations.
 * Range: 0u (Highest priority) to 3u (Lowest prioirity)
 * For more details refer to the Cortex-M0 Technical Reference Manual.
 */
#define DEF_TOUCH_PTC_ISR_LVL   (1u)

/*----------------------------------------------------------------------------
*                   Self Cap method pin configuration.
*  ----------------------------------------------------------------------------*/

/**
 * Self Cap touch channel selected.
 * The capacitance measurement is done sequentially in the order in which
 * the touch channel (nodes) are specified below.  Touch channel numbering
 * follows the order in which Y lines are specified.
 */
#define DEF_SELFCAP_LINES  Y(0), Y(1), Y(9)

/*----------------------------------------------------------------------------
*              Self Cap method channel and sensor configuration.
*  ----------------------------------------------------------------------------*/

/**
 * Self Cap number of channels.
 * Specify the number of Self Cap touch channels to be used by the Touch Library.
 * A key is formed used one touch channel.  A rotor or slider can be formed
 * using 3 touch channels.
 * Range: 1u to 16u.
 */
#define DEF_SELFCAP_NUM_CHANNELS   (3u) /* Total number of channels */

/**
 * Self Cap number of Sensors.
 * Specify the number of Self Cap touch sensors to be used by the Touch Library.
 * A sensor is either a key, rotor or slider.
 * Example configuration: If the configuration has 6 keys (a key is formed
 * using one Sensor Pin), one rotor (a Self Cap rotor is formed using 3 Sensor
 * Pins) and one slider (a Self Cap slider is formed using 3 Sensor Pins), then
 * the number of sensors is 6 key + 1 rotor + 1 slider = 8 sensors.
 * Range: 1u to 16u.
 */
#define DEF_SELFCAP_NUM_SENSORS  (1u)  /* Total number of sensors */

/**
 * Self Cap number of Rotors and Sliders.
 * Specify the total number of Self Cap Rotors and Sliders to be used by
 * the Touch Library.  The number of Rotors and Sliders mentioned here is part
 *of
 * the Total number of sensors specified in the QT_NUM_SENSORS macro.  When
 * no rotors or slider are required, specify a value of 0u.
 * Range: 0u to 8u.
 */
#define DEF_SELFCAP_NUM_ROTORS_SLIDERS  (1u)  /* Number of rotor sliders */

/*----------------------------------------------------------------------------
*                   Self Cap method aquisition parameters.
*  ----------------------------------------------------------------------------*/
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
